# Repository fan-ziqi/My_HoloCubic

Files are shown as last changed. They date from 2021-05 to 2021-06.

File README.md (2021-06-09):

## My_Holocubic

本项目基于@peng-zhihui 稚晖君的开源项目`HoloCubic`

交流群：561533565

点击链接加入群聊【稚晖君HoloCubic交流群】：https://jq.qq.com/?_wv=1027&k=dVjVTa3X

历经不到一个月，这个项目终于快要结束了，现有的软件整合了大佬们的开源方案以及自己的改动，基本实现了`时间显示`、`天气显示`、`电脑同屏`等功能。软件方面先留一个坑吧，放假了有空再继续完善，毕竟这个小东西能实现的功能还是蛮多的，只要你异想天开。

做这个项目主要有两个原因吧
* 第一是因为这个项目真的很帅有木有，也是稚晖大佬项目中算比较简单的一个，实现起来不是很复杂
* 第二，通过这个项目可以学到`ESP32的开发以及外围电路设计`、`MPU6050在ESP平台的应用`、`串口芯片CP2102代替CH340`、`LVGL图形库的使用`、`PCBLayout及TYPE-C和天线走线规则`、`3D模型设计及3D打印`、`贴片封装（QFN封装芯片、0402电阻电容、TYPE-C/FPC座）的焊接`等知识。很同意稚晖大佬的说的`边打仗边学习`，对于我来说做项目过程中知识的储备远大于平时的学习。

项目就不多介绍了，下面是原作者的项目简介：

--------------------------------------------我是一条分割线-----------------------------------------------

# HoloCubic--多功能透明显示屏桌面站

**视频介绍：** https://www.bilibili.com/video/BV1VA411p7MD/

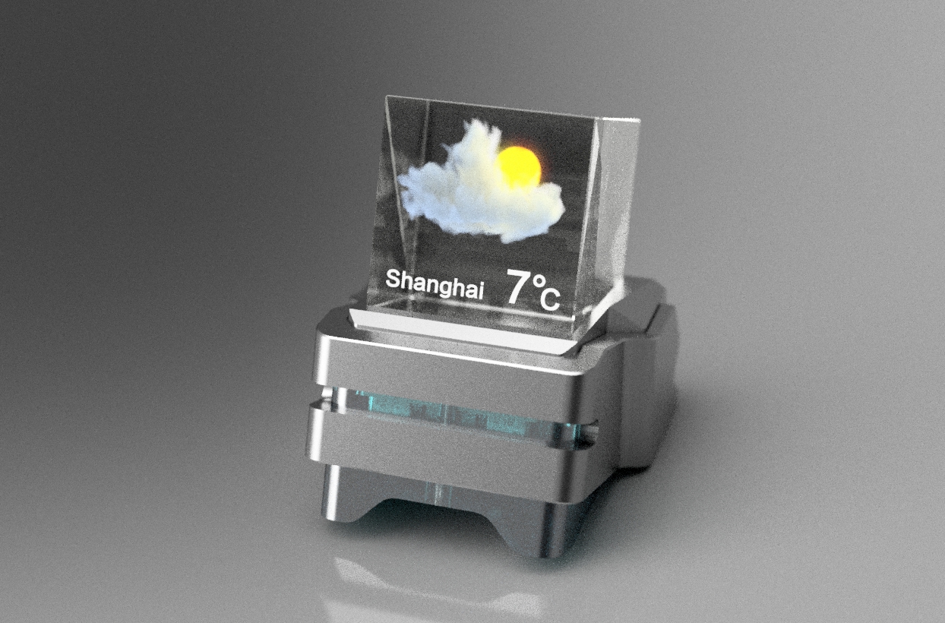
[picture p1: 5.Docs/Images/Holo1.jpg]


## 0. 关于本项目

> 稚晖君注：这是为了更新视频，缓解本人拖更两个月的尴尬，用一个周末时间赶出来的一个有意思的小玩意 :D

如视频所述，本项目有意思的地方在于使用了一个分光棱镜来设计出`伪全息显示`的效果。这个小设备总的来说功能比较多，因为搭载了WiFi和蓝牙能力可以实现很多网络应用，在本仓库中给大家提供了一个开发框架以及一些基础功能（天气、粉丝数监视器等），大家可以基于我的方案继续扩展实现更多应用。

本项目的硬件方案是基于`ESP32PICO-D4`的，乐鑫的一个很实用的MCU芯片，由于采用了SiP封装是的PCBA整板面积能做到一个硬币大小；软件方面主要是基于`lvgl-GUI`库，我移植了ST7789 1.3寸`240x240`分辨率屏幕的显示屏驱动，同时将`MPU6050`作为输入设备通过感应的方式模拟编码器键值来交互。

## 1. 硬件打样说明

**PCB打样的话暂时没发现有啥需要特别注意的。** PCB文件可以直接拿去工厂打样，两层板很便宜，器件BOM的话也都是比较常用的，整板成本在50元以内。

`Hardware`文件内目前包含两个版本的PCB电路：

* **Naive Version** ：即视频中出现的版本，板载ESP32、IMU、环境光传感器、SD卡槽、下载电路、以及两个RGB灯
* **Ironman Version** ：基于上面的版本轻微修改，删去了环境光传感器，修改了PCB形状以适配新的外壳

> 因为新款的外壳计划是使用CNC进行金属加工，因此环境光容易被遮挡，而且该功能使用场景不多所以在新版删去了。

**外壳加工** 根据自己喜欢的版本选择，`3D Model`文件夹目前包含四个版本的外壳文件：

* **Naive Version** ：即视频中出现的版本，比较简约（因为临时赶工设计的），最好使用光固化3D打印加工

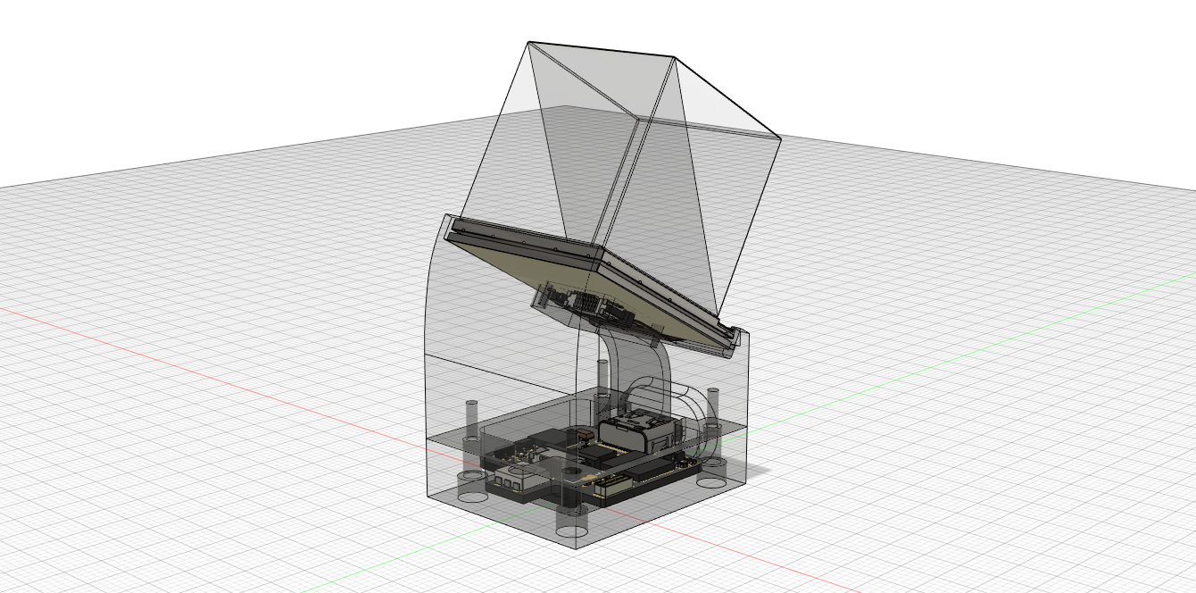
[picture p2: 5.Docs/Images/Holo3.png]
  

* **Bilibili Version** ：视频中后面出现的B站百大奖杯形式的外壳结构，适配`Naive Version`的PCB， **属于娱乐性质，非百大UP不建议采用**。

* **Metal Version** ：视频发布后全新改版的外壳结构设计，优化了布局控件整体更紧凑精致，适配`Naive Version`的PCB，该建议使用CNC加工制作

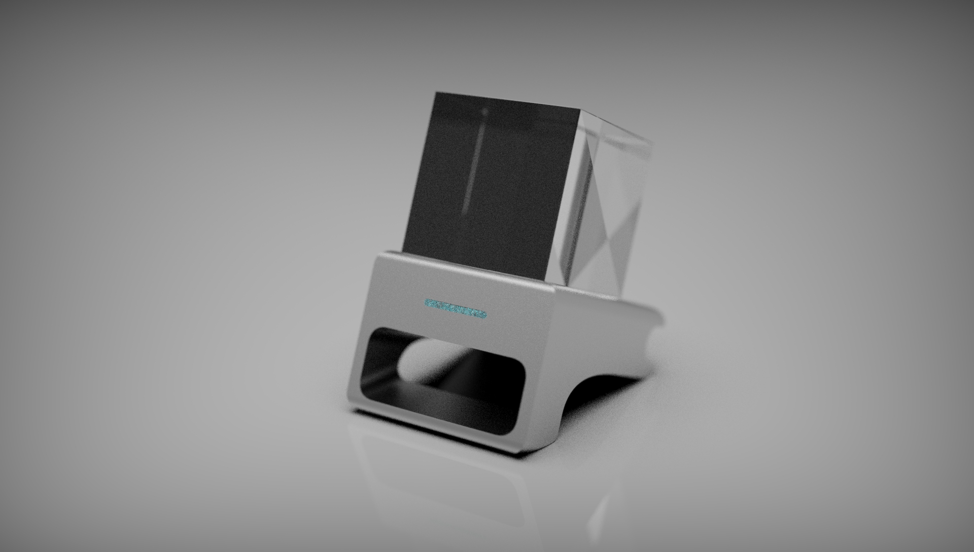
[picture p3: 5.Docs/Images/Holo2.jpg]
  

* **Ironman Version** ：新设计的野生钢铁侠风格结构件，该版本为和朋友合作设计的，后面可能会授权他联名量产，该结构适配`Ironman Version`的PCB

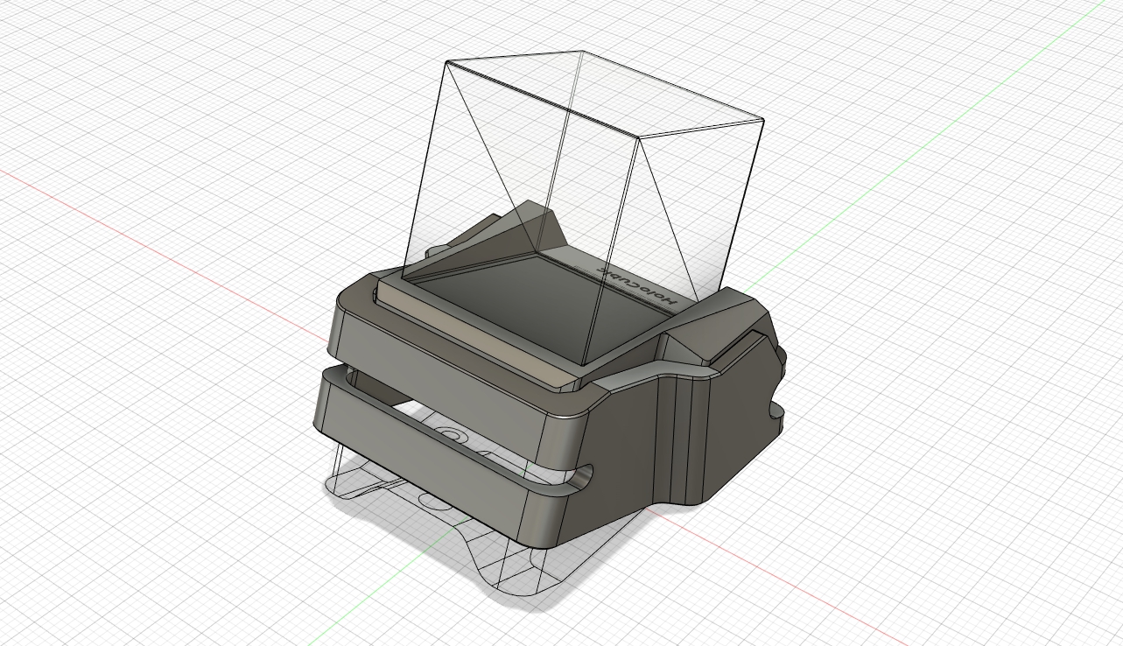
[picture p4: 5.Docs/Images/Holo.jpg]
  

> 野生钢铁侠联名的版本的结构件加工比较复杂，而且需要后期喷砂、阳极氧化等工艺所以单件制造成本很高（打听了下整套3个部件至少要1000元+），因此大家自己有加工渠道的可以用提供的文件自己去做。
>
> 没有渠道但是又想要这个版本硬件的，**我授权了那位朋友量产一小批**，他的店铺名为[Xikii](https://shop68240117.taobao.com)，是做客制化键盘很有经验的一个极客，大家感兴趣的可以去关注一下~

## 2. 固件编译说明

固件框架主要基于Arduino开发完成，玩过Arduino的基本没有上手难度了，把Firmware/Libraries里面的库安装到Arduino库目录（如果你用的是Arduino IDE的话）即可。

> 我使用的是Visual Studio上面的Visual Micro插件进行Arduino开发，因为对VS比较熟悉，大家选择自己喜欢的IDE就好了。

**然后这里需要修改一个官方库文件才能正常使用：**

首先肯定得安装ESP32的Arduino支持包（百度有海量教程），然后在安装的支持包的`esp32\hardware\esp32\1.0.4\libraries\SPI\src\SPI.cpp`文件中，**修改以下代码中的MISO为26**：

    if(sck == -1 && miso == -1 && mosi == -1 && ss == -1) {
        _sck = (_spi_num == VSPI) ? SCK : 14;
        _miso = (_spi_num == VSPI) ? MISO : 12; // 需要改为26
        _mosi = (_spi_num == VSPI) ? MOSI : 13;
        _ss = (_spi_num == VSPI) ? SS : 15;
这是因为，硬件上连接屏幕和SD卡分别是用两个硬件SPI，其中HSPI的默认MISO引脚是12，而12在ESP32中是用于上电时设置flash电平的，上电之前上拉会导致芯片无法启动，因此我们将默认的引脚替换为26。

> 也可以通过设置芯片熔丝的方式解决这个问题，不过那样的操作是一次性不可逆的，不建议这么玩。

**另外：**

由于我赶视频制作，代码都是临时写的非常杂乱有很多dirty code，因此仓库中的是所有驱动调通之后的模板代码，可以自己基于这个框架自由开发。

**APP应用代码我在整理中慢慢也会更新出来。**

## 3. Visual Studio模拟器 & 图片转换脚本

在`Software`文件夹中包含了一个Visual Studio的工程，用VS打开（需要安装C++开发组件）后可以在电脑上模拟LVGL的界面效果，改好之后代码粘贴到Arduino固件那边就可以完成界面移植。

> 这样省的每次修改都要重新交叉编译Arduino的固件，提升开发效率。

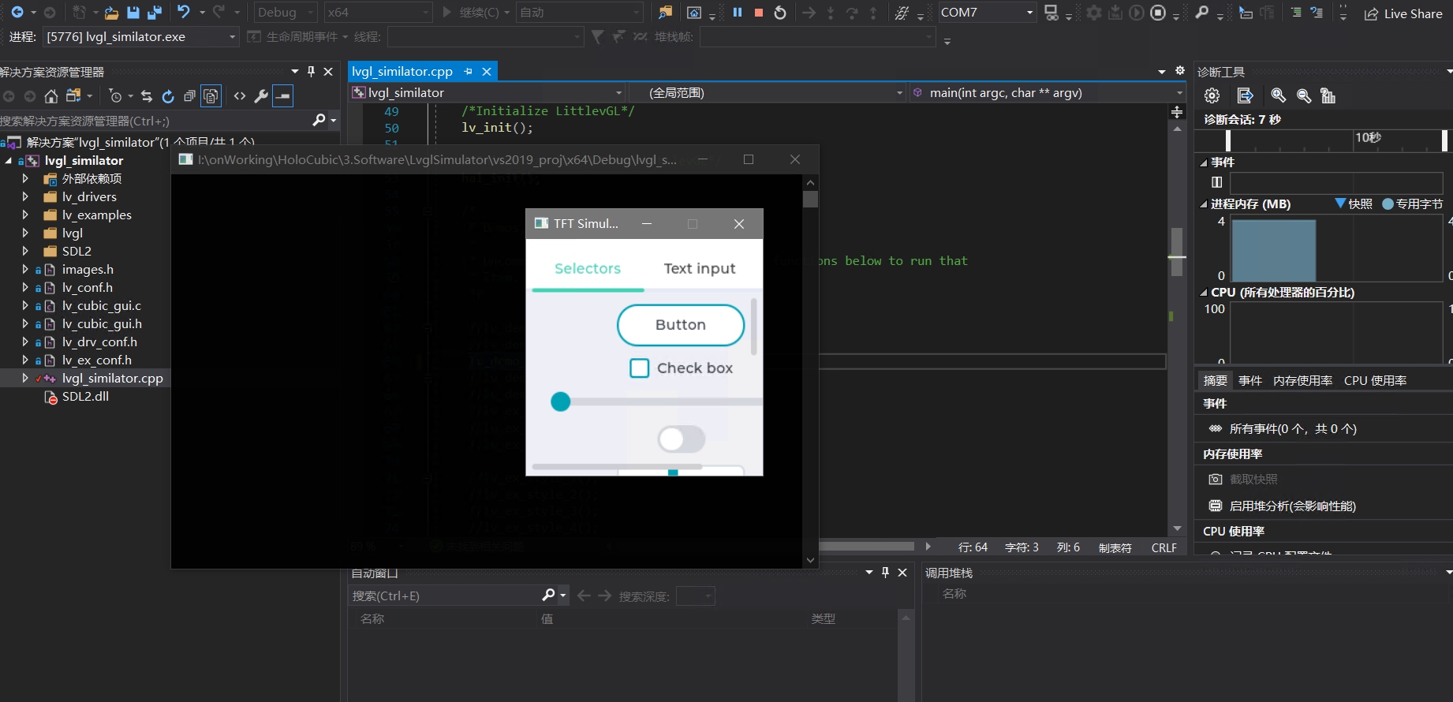
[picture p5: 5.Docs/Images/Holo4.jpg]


`ImageToHolo`文件夹下包含一个Python脚本，用于将图片转换成HoloCubic固件中用到的图像资源。

> 因为图像资源一般都比较占空间，如果全部存在ESP32的Flash中的话存不了几张，因此我在框架中移植了LVGL的FAT文件系统支持，可以将图片资源存储在SD卡内进行读取。
>
> 官方的图转换工具是在线的：[https://lvgl.io/tools/imageconverter](https://lvgl.io/tools/imageconverter) ，需要选择 `Indexed 4 colors` 格式。
>
> **但是官方工具每次只能转换一张还要上传下载很麻烦**，因此我自己写了个脚本用于批量转换。

HoloCubic用到的图片资源名为`xxx.bin`文件，大家用我提供的脚本转好后放入SD卡，然后可以像这样读取：

```
lv_obj_t* imgbtn = lv_imgbtn_create(lv_scr_act(), NULL);
lv_imgbtn_set_src(imgbtn, LV_BTN_STATE_PRESSED, "S:/dir/icon_pressed.bin");
lv_imgbtn_set_src(imgbtn, LV_BTN_STATE_RELEASED, "S:/dir/icon_released.bin");
```

其中`S:`指代SD卡根目录（注意**S是大写的**），后面就是跟Linux中的路径完全表示一致了。

> 该脚本参考了[W-Mai/lvgl_image_converter](https://github.com/W-Mai/lvgl_image_converter) 的实现。

**另外由于转换脚本的使用需要再Python环境下，如果大家不想安装环境的话，也可以用我预编译好的exe文件来转，使用方法很简单，把`jpg/png/bmp`图片拖到`holo转换器.exe`的图标上就行了（可以同时拖动多个上去），会在当前目录生成对应的`.bin`文件。**

> 转换器软件的下载地址：
>
> 链接：https://pan.baidu.com/s/11cPOVYnKkxmd88o-Ouwb5g  提取码：xlju 

## 4. 关于分光棱镜

我用的时25.4mm x 25.4mm x 25.4mm的棱镜，淘宝应该可以搜到，单个价格80元左右。

分光棱镜的固定比较麻烦，用胶水的话容易渗入屏幕导致水印，因此建议去TB搜一下`OCA胶`，这是一种`全贴合屏幕工艺`中用来粘合屏幕的固态胶，效果很不错也很便宜。

> 但是OCA粘性非常强，大家操作一定要仔细不要留气泡，不然粘上后就很难取下了。

## 其他的后续再补充，有用的话记得点星星~

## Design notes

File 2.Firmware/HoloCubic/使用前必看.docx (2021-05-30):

# ESP32相册、天气、时间显示

1. 如需使用本程序，请在arduino官网下载arduino ide，如果使用的是VS code进行编译，请见附页教程。

本项目目前实现的功能有以下几种：

1.ESP32一键配网：第一次使用，可以连接ESP32的热点进入“192.168.4.1”进行wifi的账号密码以及城市名配置

2.ESP32陀螺仪控制：在本项目主要用于切换显示

3.ESP32天气显示：在界面中，采用“心知天气”API进行天气信息获取。

4.ESP32时间显示：在界面中，采用“淘宝”API进行时间信息获取。

5.ESP32相册显示

2. 首先打开arduino ide后进入首选项配置

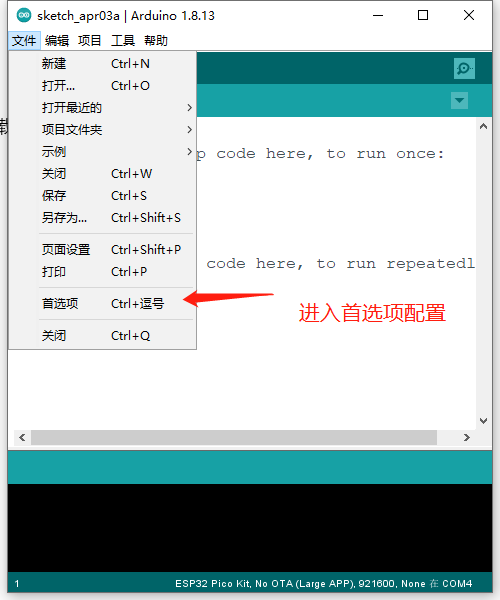
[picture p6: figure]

在“附加开发板管理器网址”中添加 “https://dl.espressif.com/dl/package_esp32_index.json”

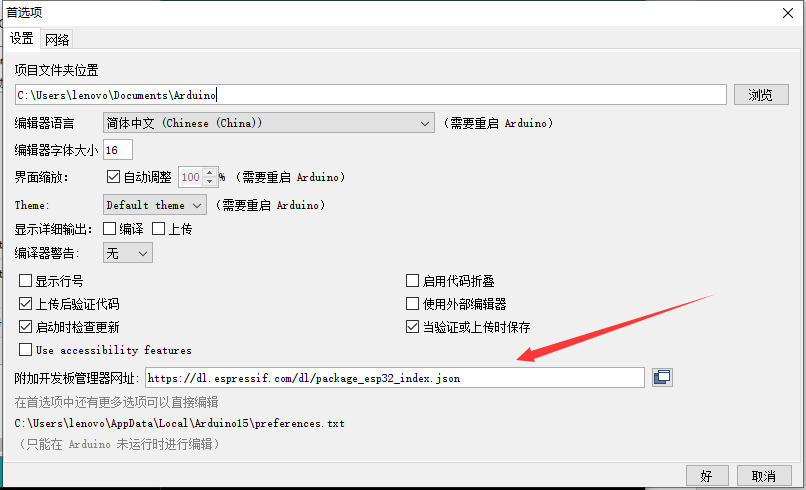
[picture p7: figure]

之后打开“工具”中的“开发板管理器”

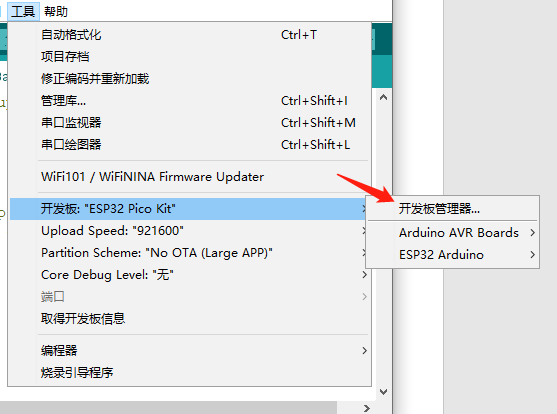
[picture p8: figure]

下载ESP32开发板,我这里已经下载了，所以显示的是更新，如果没有下载就安装一下，安装时候安装最新版本即可，否则可能有些功能无法使用。

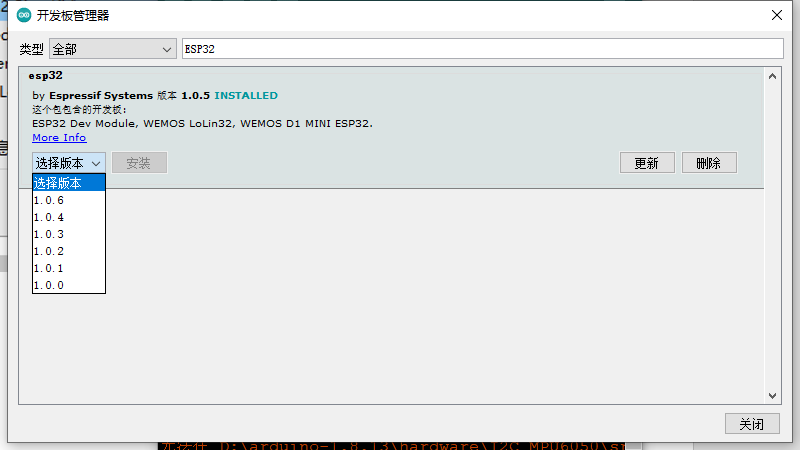
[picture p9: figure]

随后将文件夹内带的“Libraries”文件夹内的库文件放到“C:\Users\lenovo\Documents\Arduino\libraries”即可使用。

注意，使用此程序需要将工具中的“Partition Scheme”设置为“NO OTA”模式。

# ESP32一键配网

此功能主要是分为两部分，首先上电后会检测SD卡的wifi.txt文件是否有已配置的内容，如果有则尝试连接，连接成功后会进入页面显示。如果连接不成功则进入AP热点配网模式，ESP32会自身开启热点，用户连接热点后进行wifi的配置。

热点默认ssid为“ESP32_Config”，默认密码为“12345678”，进入默认ip地址“192.168.4.1”即可配置“WiFi SSID”、“WiFi PASS”、“City Name”三个参数，City Name参数主要作为天气显示调用api时上传的位置信息。

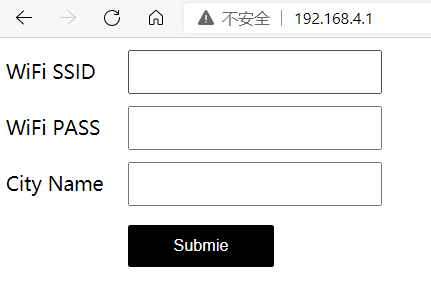
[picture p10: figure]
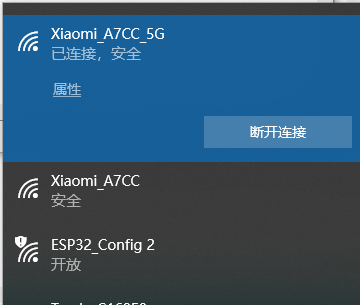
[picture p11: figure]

填写完成后使用“GET”协议下发到ESP32上，随后存储进SD卡内。下次会自动检测是否有上次配置的wifi环境，如果有会自动重连。中间断线也可重新连接。

# ESP32陀螺仪控制

此设备装载MPU6050陀螺仪，可以检测 6自由度或6轴的IMU传感器，这意味着它提供了6个值作为输出：包含加速度计的3个值和陀螺仪的3个值。MPU 6050是一种基于MEMS（微机电系统）技术的传感器，它将加速度计和陀螺仪嵌入到一块芯片中，芯片使用的I2C通信协议。

在本项目中主要用于角度感知，利用x轴和y轴的变化来控制页面的切换。如果自己感觉角度灵敏可以调节imu.cpp文件下的ax和ay的判定数值。

# ESP32天气显示

天气显示主要运用lvgl库来对屏幕进行绘制，数据的获取主要获取的“心知天气”的天气api数据“ https://api.seniverse.com/v3/weather/now.json?key=" + key + "&location=" + cityname + "&language=" + language + "&unit=" + unit”，如需使用请申请心知天气账号，可以免费开通天气api，不过有访问频率限制，所以此处不公开私钥了，在程序中把自己的私钥赋值给给37行的“key”变量即可。

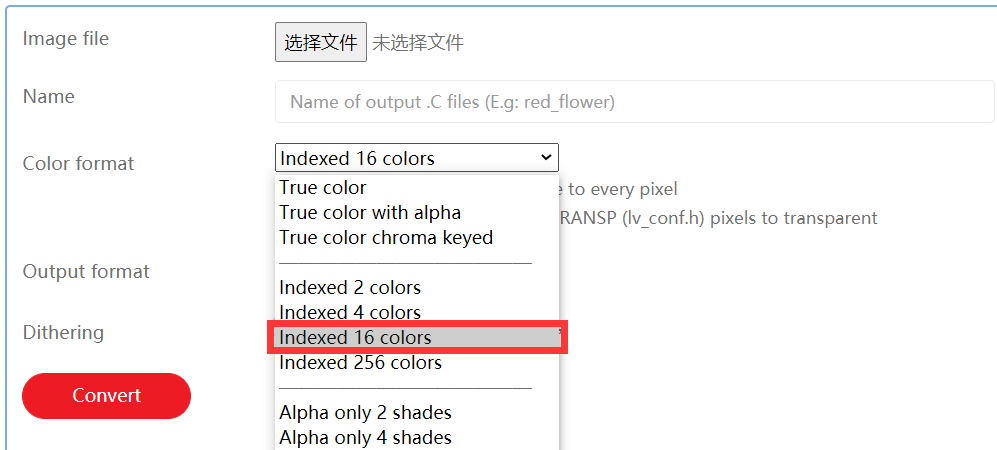
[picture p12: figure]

常用的天气图片利用lvgl的官方转换器https://lvgl.io/tools/imageconverter 转换为c数组，格式为Indexed 16 colors。

随后把转换完成的c文件复制下来粘贴到image.h文件中，复制格式与程序中相同即可。

注：图片分辨率需为240*240，否则屏幕则显示不下相应图片。

不常用的图片则可以转换成bin文件存储到SD卡中，这样可以省下一些程序存储空间用来增加功能。

转换格式为下图的标准格式，本程序内涵weather文件夹，已做好image转换。如果想要自己重新制作一套，需参照心知天气的天气代码来重新生成文件，文件名对应其天气代码即可。

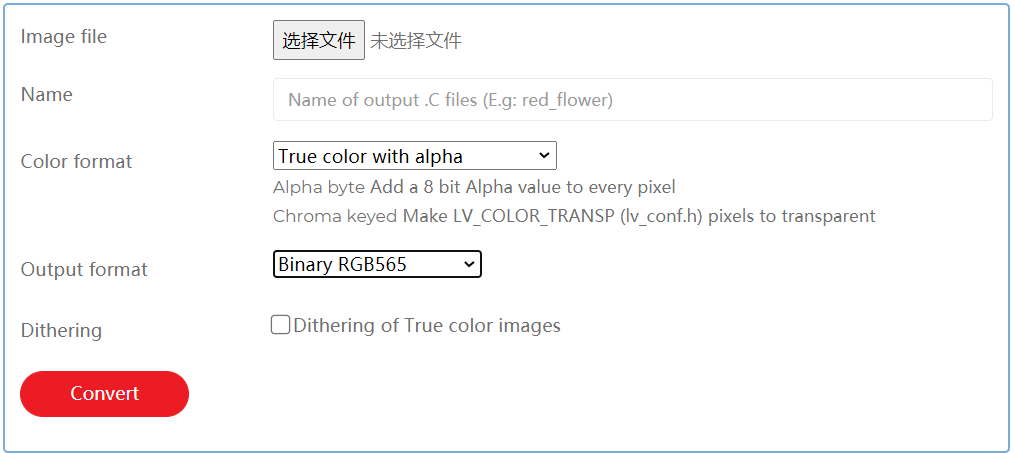
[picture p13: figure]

# ESP32时间显示

此功能主要采集的“淘宝”的时间api http://api.m.taobao.com/rest/api3.do?api=mtop.common.getTimestamp，此api免费使用，所以不必担心期限问题。在程序中利用arduino的rtc.setTime(Time);函数来进行时间的计算，把采集到的“data”数据传入到此函数中，会返回对应的年月日时分。在显示上加了一个字符串拼接，因为在时间分小于10的时候，在分的个位前没有0的显示，所以加了一个字符串拼接来显示0。字体则使用的为lvgl自带的字体。

# ESP32相册显示

此功能读取的为SD卡中image文件夹下的bin文件，将自己的图片在官网转换，转换格式为下图，需要自己修改文件名格式为（0.bin，1.bin，2.bin，3.bin……）。随后对ESP32进行上倾斜（x轴）就可进入相册显示界面，下倾斜（x轴）则退出相册显示，进入常规显示。

目前现在相册可以存储250张，如果认为空间不够使用，请更改SdCard.cpp文件下listDir函数内的“File_name”数组的空间大小即可。

建议最大不要超过10000，这样会比较浪费内存空间。

后续功能待开发……

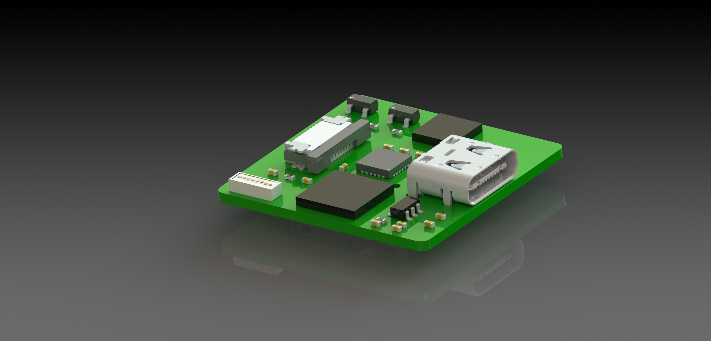
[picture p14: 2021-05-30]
1.Hardware/PCB/HoloCubic/Untitled.JPG

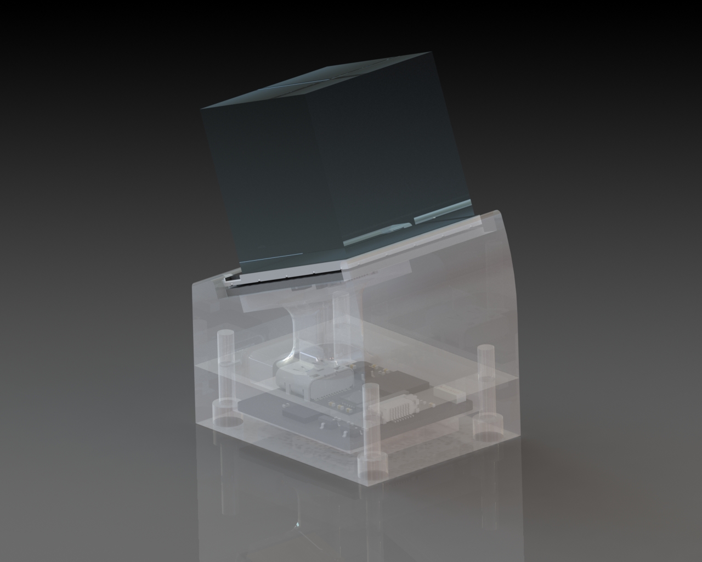
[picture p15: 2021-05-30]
4.3D_Model/SW/渲染.JPG

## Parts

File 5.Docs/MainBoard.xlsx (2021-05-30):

Comment | Description | Designator | Footprint | LibRef | Quantity
2.2nF | Capacitor | C8 | CAP_0402 | 电容-0402 | 1 | 15
10nF | Capacitor | C3, C6 | CAP_0402 | 电容-0402 | 2 | 30
100nf | Capacitor | C1, C5, C7, C10, C11 | CAP_0402 | 电容-0402 | 3 | 45
1uF | Capacitor | C9 | CAP_0402 | 电容-0402 | 1 | 15
10uF | Capacitor | C2, C4 | CAP_0402 | 电容-0402 | 2 | 30
0R | Resistor | R2 | RES_0402 | 电阻-0402 | 1 | 15
200R | Resistor | R3 | RES_0402 | 电阻-0402 | 1 | 15
10K | Resistor | R1, R6, R7, R8, R9, R10 | RES_0402 | 电阻-0402 | 6 | 90
12K | Resistor | R4, R5 | RES_0402 | 电阻-0402 | 2 | 30
CP2102 | USB转TTL | U1 | QFN-28 | CP2102 | 1 |  | 3
MPU6050 | 六轴传感器 | U3 | QFN-24 | MPU6050 | 1 |  | 4
ESP32_SIP |  | U4 | QFN-48_7X7 | ESP32-PICO | 1 |  | 4
LP2992 3V3 | LDO | U2 | SOT23-5 | LP2992 | 1
S8050 |  | VT1, VT2 | SMT_TRIODE_NPN | SMT_TRIODE_NPN | 2
RAINSUN |  | A1 | ANT-Rainsun-AN5120 | ANT-Rainsun-AP5120 | 1
4x4x1.5 | 贴片4x4轻触开关 | KEY1 |  | TSW SMD-4x4 | 1
TF_Card | TF卡座 | TF1 | Micro SD | TF_Card | 1
Type-C |  | USB1 | Type-C-TOP | USB-Type-C-TOP | 1
FFC_0.5_8 | FFC | CON1 | FFC_0.5_8 | FFC_0.5_8 | 1

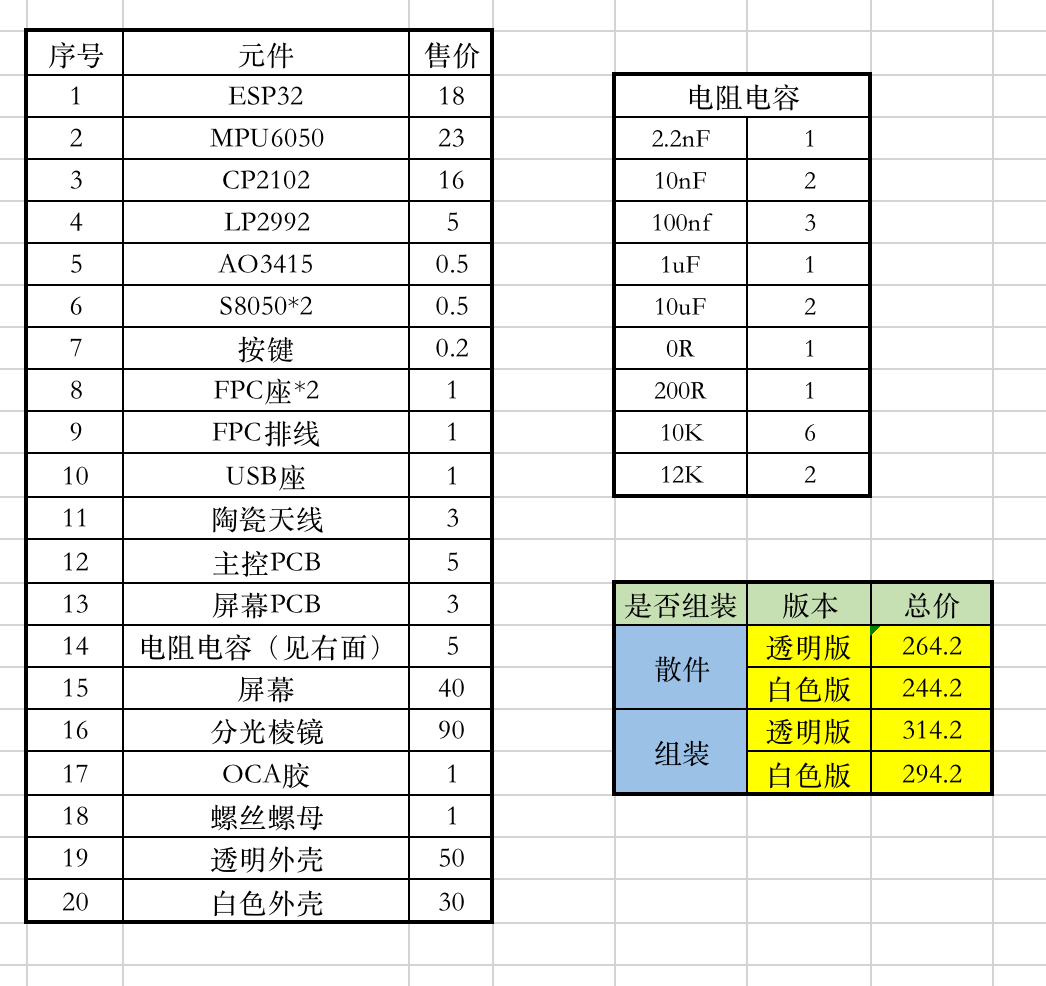
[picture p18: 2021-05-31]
销售清单.png

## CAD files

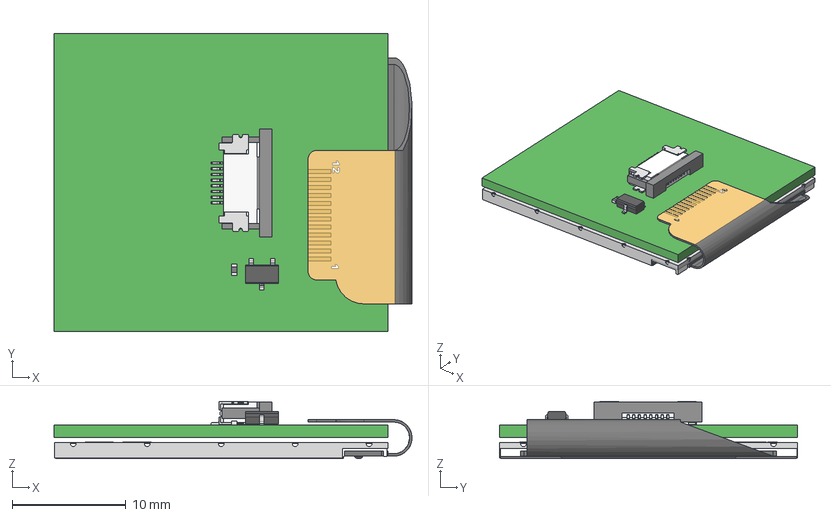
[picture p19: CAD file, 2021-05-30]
1.Hardware/PCB/HoloCubic/LCD/LCD.step
31.5 x 26.2 x 5.03 mm
Mid_Body
Open_CASCADE_STEP_translator_6.8_20.2.1 x 2
Mark
SOT-23-3
ffc_fpc_affc20-16-050-shb-t_(2)
1.3_TFT_IPS_-_Flush_Reverse_Mount

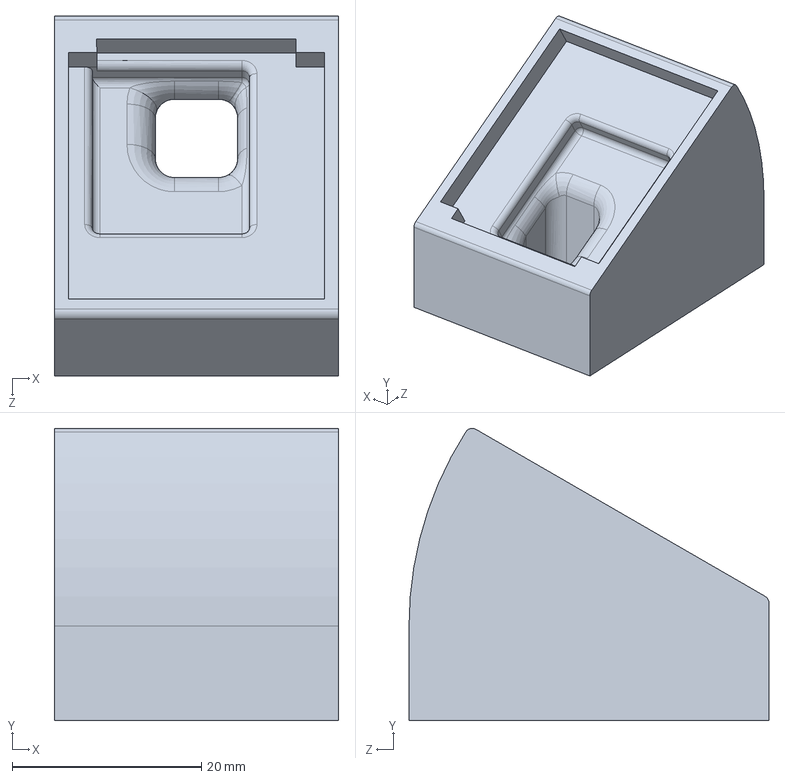
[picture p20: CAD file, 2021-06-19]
4.3D_Model/SW/up.SLDPRT
30.0 x 30.9 x 38.0 mm

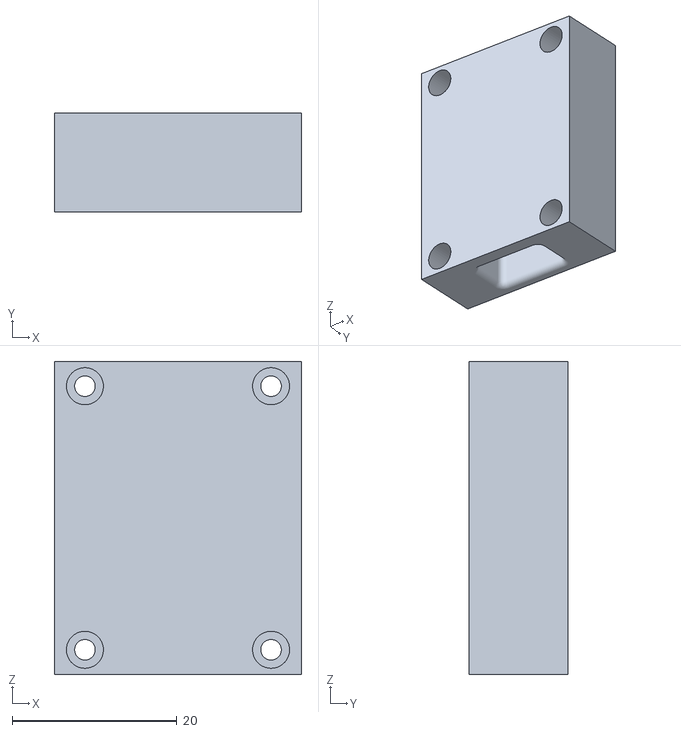
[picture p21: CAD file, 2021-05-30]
4.3D_Model/low.STL
30.0 x 12.0 x 38.0

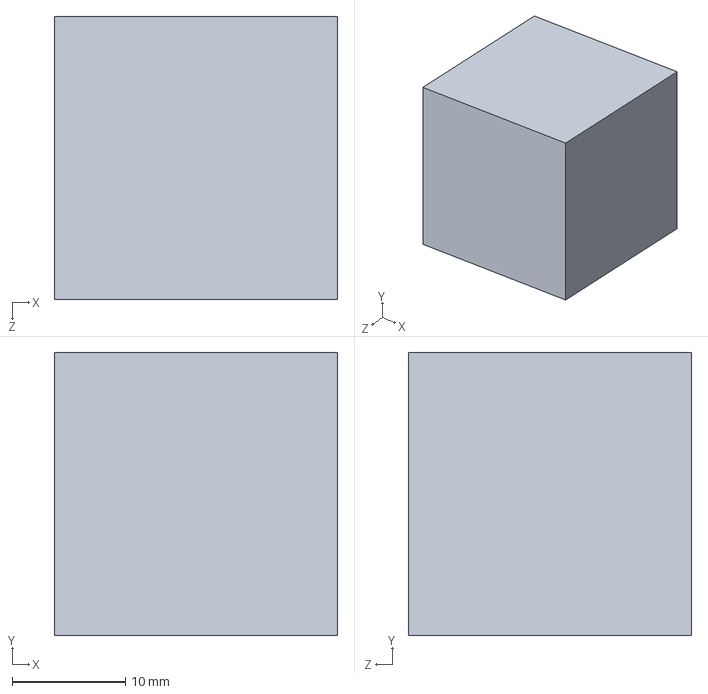
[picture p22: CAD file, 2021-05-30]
4.3D_Model/SW/CUBE.SLDPRT
25.0 x 25.0 x 25.0 mm

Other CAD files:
4.3D_Model/up_4_0.STL
4.3D_Model/SW/up_4_0.SLDPRT
4.3D_Model/up.STL
4.3D_Model/SW/low.SLDPRT
4.3D_Model/SW/up.STL

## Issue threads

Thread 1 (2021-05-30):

BUGs

fan-ziqi, 2021-05-30:
请在此提交软硬件bug，也可创建新issue，我看到后会邮箱回复

fan-ziqi, 2021-05-30:
作者太帅怎么办？

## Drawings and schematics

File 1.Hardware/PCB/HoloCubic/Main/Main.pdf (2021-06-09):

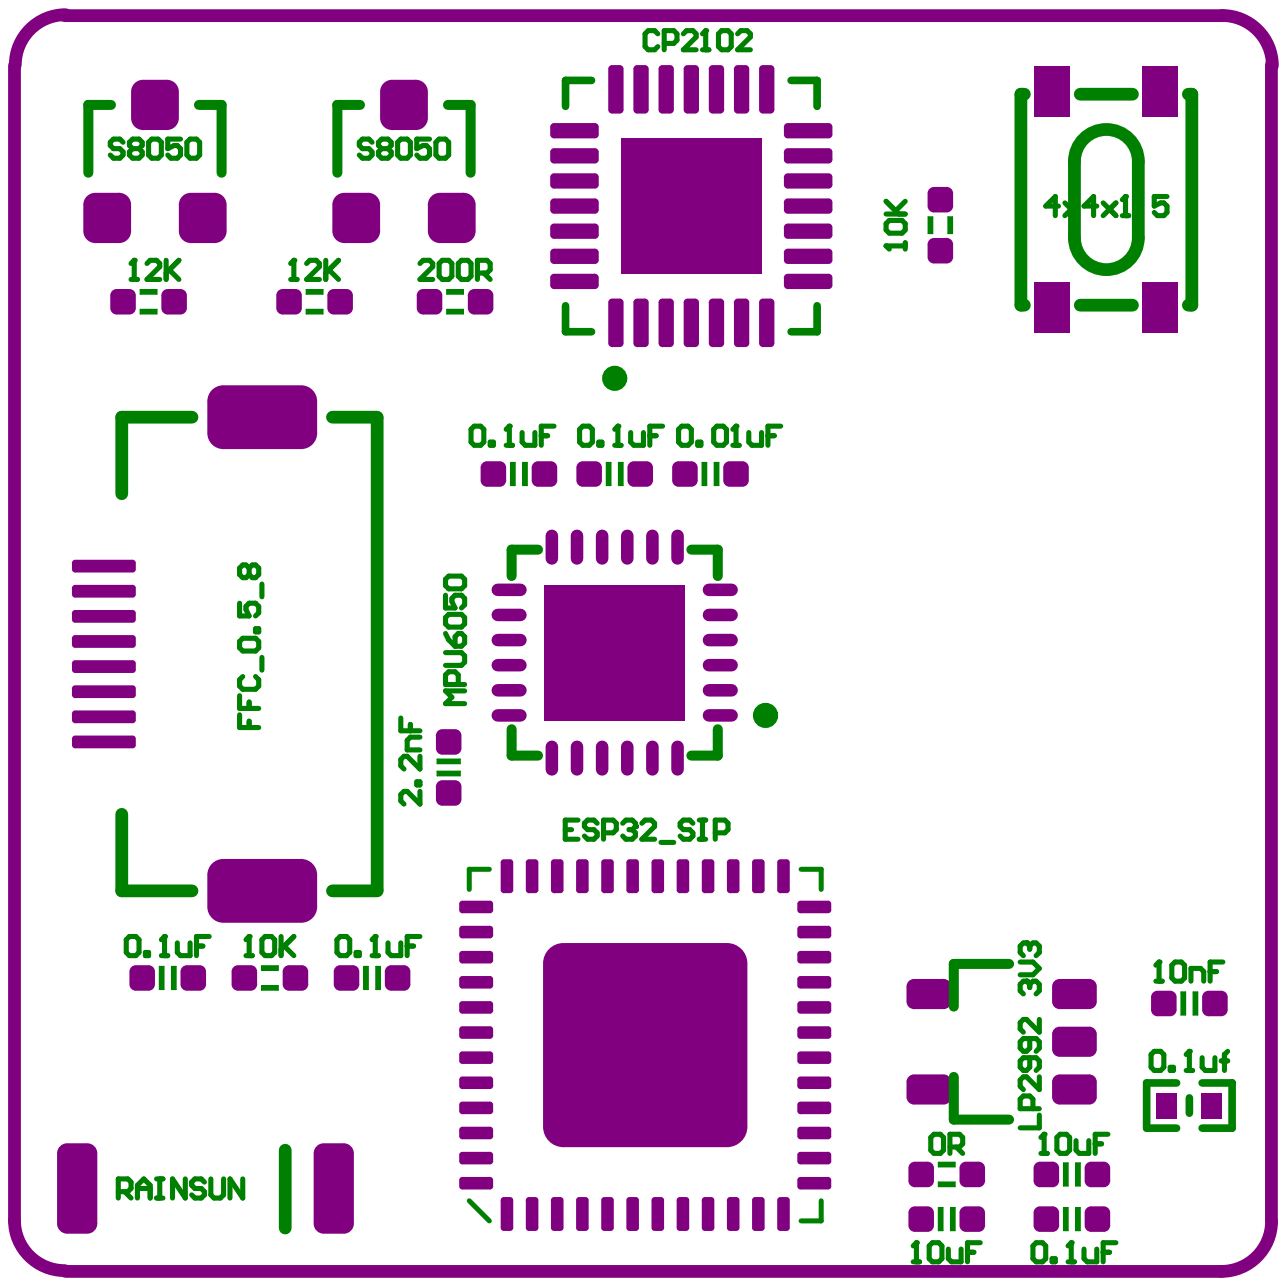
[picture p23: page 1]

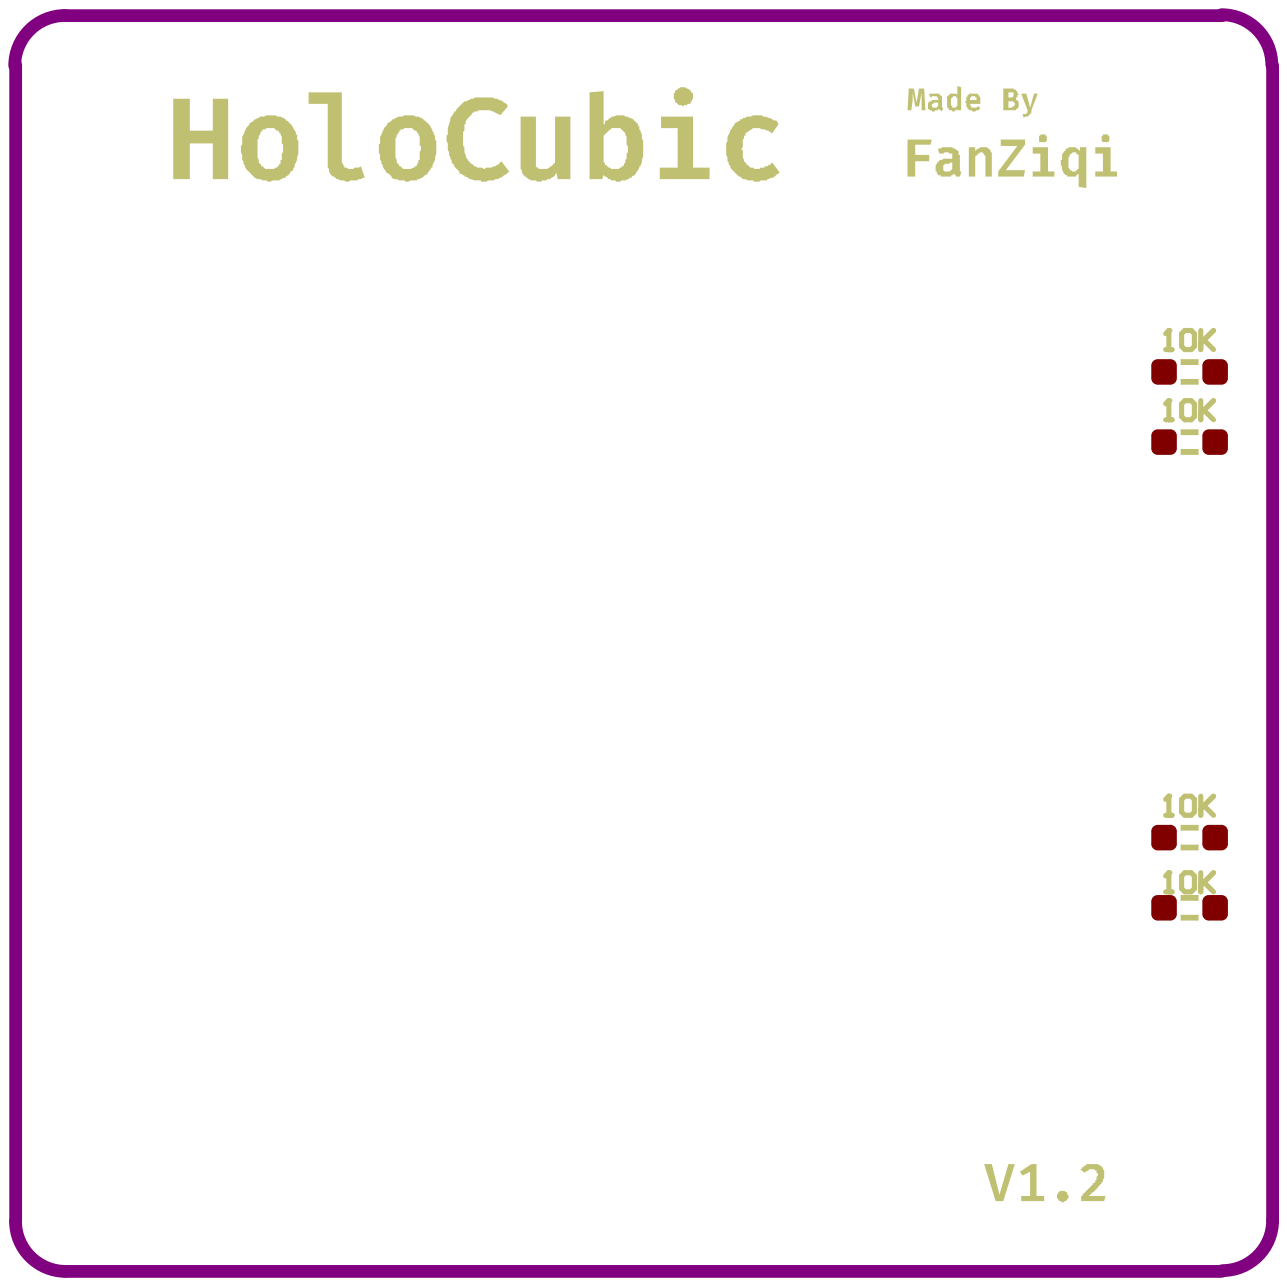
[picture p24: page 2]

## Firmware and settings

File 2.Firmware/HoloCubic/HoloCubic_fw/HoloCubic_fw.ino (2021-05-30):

#include "display.h"
#include "imu.h"
#include "network.h"
#include "sd_card.h"
#include "lv_port_indev.h"
#include "lv_cubic_gui.h"
#include "lv_demo_encoder.h"
#include "lv_port_fatfs.h"
#include <ESP32Time.h>
#include <ESPmDNS.h>
#include <WebServer.h>
#include <WiFiMulti.h>

#include <TFT_eSPI.h>
extern TFT_eSPI tft;
TFT_eSprite clk = TFT_eSprite(&tft);

/*** Component objects **7*/
Display screen;
IMU mpu;
SdCard tf;
Network wifi;
ESP32Time rtc;
long int Time;
int tian;
int zero_flag;
long time1;
const char* AP_SSID  = "ESP32_Config"; //热点名称
const char* AP_PASS  = "12345678";  //密码
#define ROOT_HTML  "<!DOCTYPE html><html><head><title>WIFI Config by lwang</title><meta name=\"viewport\" content=\"width=device-width, initial-scale=1\"></head><style type=\"text/css\">.input{display: block; margin-top: 10px;}.input span{width: 100px; float: left; float: left; height: 36px; line-height: 36px;}.input input{height: 30px;width: 200px;}.btn{width: 120px; height: 35px; background-color: #000000; border:0px; color:#ffffff; margin-top:15px; margin-left:100px;}</style><body><form method=\"GET\" action=\"connect\"><label class=\"input\"><span>WiFi SSID</span><input type=\"text\" name=\"ssid\"></label><label class=\"input\"><span>WiFi PASS</span><input type=\"text\"  name=\"pass\"></label><label class=\"input\"><span>City Name</span><input type=\"text\" name=\"cityname\"></label></label><input class=\"btn\" type=\"submit\" name=\"submit\" value=\"Submie\"></form></body></html>"
WebServer server(80);
TimerHandle_t xTimer_rest;
WiFiMulti wifiMulti;
uint8_t count_down;//自动配网倒计时s
uint8_t wifi_flag;
uint8_t resr_count_down = 100;//重启倒计时s
String  key = "SqTlWHkGy6Ig6XcZG"; //填写天气秘钥
String  cityname;		 //显示的城市
String  language = "zh-Hans";
String  unit = "c";
String Time_api = "http://api.m.taobao.com/rest/api3.do?api=mtop.common.getTimestamp";
int Timey;
int Timem;
int Timed;
int Timeh;
int Timemin;

char Timey1[8];
char Timem1[8];
char Timed1[8];
char Timeh1[8];
char Timemin1[8];
char zero[8];
char tiangqii[8];
char cityname1[10];

const char* Timey2 = Timey1;
const char* Timem2 = Timem1;
const char* Timed2 = Timed1;
const char* Timeh2 = Timeh1;
const char* Timemin2 = Timemin1;
const char* zeroo = zero;
const char* tianqq = tiangqii;



void restCallback(TimerHandle_t xTimer );
////####################################################################################################
//// 文件上传SD卡
////####################################################################################################
//void handleFileUpload(){//网络服务处理函数
//  upload_flag = true;//正在进行上传
//  if(server.uri() != "/") return;
//  HTTPUpload& upload = server.upload();
//  String filename;
//  char *file_sd;
//  if(upload.status == UPLOAD_FILE_START){//开启下载上传的文件
//    filename = upload.filename;
//    if(!filename.startsWith("/"))
//    {
//      filename = "/loge"+String(tft_num)+".jpg";//如果文件开头没有/则添加/ 并且对该图片添加计数尾缀
//      tft_num++;//文件数+1
//      EEPROM.write(20,tft_num);//将数据保存
//      EEPROM.commit();
//    }
//    Serial.print("handleFileUpload Name: "); Serial.println(filename);//打印文件名
//
//    SD.remove(filename);
//    fsUploadFile = SD.open(filename, "w");//将上传的文件保存
//    filename = String();
//  } else if(upload.status == UPLOAD_FILE_WRITE){
//    if(fsUploadFile)
//      fsUploadFile.write(upload.buf, upload.currentSize);//将上传文件写入SD卡
//  } else if(upload.status == UPLOAD_FILE_END){
//    if(fsUploadFile)
//      fsUploadFile.close();
//  }
//}
void UpdateWeather(void)
{
  int TianQi = wifi.getTianqi("https://api.seniverse.com/v3/weather/now.json?key=" + key + "&location=" + cityname + "&language=" + language + "&unit=" + unit); //如果要改城市这里也需要修改
  itoa(TianQi, tiangqii, 10);
  Serial.println(tian);
  lv_holo_cubic_gui(tianqq, Timey2, Timem2, Timed2, Timeh2, Timemin2, cityname.c_str(), 1, WeatherCode);
}

void UpdateTime_RTC(void)
{
  Timey = rtc.getYear();
  Timem = rtc.getMonth() + 1;
  Timed = rtc.getDay();
  Timeh = rtc.getHour(true) + 8;
  Timemin = rtc.getMinute();
  itoa(Timey, Timey1, 10);
  itoa(Timem, Timem1, 10);
  itoa(Timed, Timed1, 10);
  itoa(Timeh, Timeh1, 10);
  itoa(Timemin, Timemin1, 10);
  if (Timemin < 10)
  {
    strcpy(zero, "0");
    strcat(zero,Timemin1);
    strcpy(Timemin1,zero);
  }
  lv_holo_cubic_gui(tianqq, Timey2, Timem2, Timed2, Timeh2, Timemin2, cityname.c_str(), 2, WeatherCode);
}
void ap_jiance(boolean result)
{
  if (result)
  {
    IPAddress myIP = WiFi.softAPIP();

    //打印相关信息

    Serial.println("");

    Serial.print("Soft-AP IP address = ");

    Serial.println(myIP);

    Serial.println(String("MAC address = ")  + WiFi.softAPmacAddress().c_str());

    Serial.println("waiting ...");

    xTimer_rest = xTimerCreate("xTimer_rest", 1000 / portTICK_PERIOD_MS, pdTRUE, ( void * ) 0, restCallback);

    xTimerStart( xTimer_rest, 0 );  //开启定时器


  } else {  //开启热点失败

    Serial.println("WiFiAP Failed");

    delay(3000);

    ESP.restart();  //复位esp32

  }
  if (MDNS.begin("esp32")) {

    Serial.println("MDNS responder started");
  }
}
void wifi_cun(String ssid, String pass, String cityname)
{
  tf.deleteFile("/wifi.txt");
  tf.writeFile("/wifi.txt", ssid.c_str(), pass.c_str(), cityname.c_str());
  String ssid_txt = tf.readFileLine("/wifi.txt", 1);    // line-1 for WiFi ssid
  String password_txt = tf.readFileLine("/wifi.txt", 2);  // line-2 for WiFi password
  cityname = tf.readFileLine("/wifi.txt", 3);  // line-3 for tianqi
  Serial.println(ssid_txt);
  Serial.println(password_txt);
  Serial.println(cityname);
  tian = wifi.getTianqi("https://api.seniverse.com/v3/weather/now.json?key=" + key + "&location=" + cityname + "&language=" + language + "&unit=" + unit);
  Serial.println(tian);
  Time = wifi.getTimestamp(Time_api); //nowapi时间API
  Serial.println(Time);
  rtc.setTime(Time);

  char tiangqi[8];
  /*About Time Start*/

  Timey = rtc.getYear();
  Timem = rtc.getMonth() + 1;
  Timed = rtc.getDay();
  Timeh = rtc.getHour(true) + 8;
  Timemin = rtc.getMinute();
  itoa(Timey, Timey1, 10);
  itoa(Timem, Timem1, 10);
  itoa(Timed, Timed1, 10);
  itoa(Timeh, Timeh1, 10);
  itoa(Timemin, Timemin1, 10);
  if (Timemin < 10)
  {
    strcpy(zero, "0");
    strcat(zero,Timemin1);
    strcpy(Timemin1,zero);
  }
  itoa(tian, tiangqi, 10);
  const char* tianq = tiangqi;

  Serial.println("-------------------------------------");
  Serial.println(tianq);
  Serial.println(Timey2);
  Serial.println(Timem2);
  Serial.println(Timed2);
  Serial.println(Timeh2);
  Serial.println(Timemin2);
  Serial.println(cityname);
  Serial.println(0);
  Serial.println(WeatherCode);
  Serial.println("-------------------------------------");
  lv_holo_cubic_gui(tianq, Timey2, Timem2, Timed2, Timeh2, Timemin2, cityname.c_str(), 0, WeatherCode);
}
void wifi_getdata()
{
  tian = wifi.getTianqi("https://api.seniverse.com/v3/weather/now.json?key=" + key + "&location=" + cityname + "&language=" + language + "&unit=" + unit);
  Serial.println(tian);
  Time = wifi.getTimestamp(Time_api); //nowapi时间API
  Serial.println(Time);
  rtc.setTime(Time);
  char tiangqi[8];
  /*About Time Start*/
  Timey = rtc.getYear();
  Timem = rtc.getMonth() + 1;
  Timed = rtc.getDay();
  Timeh = rtc.getHour(true) + 8;
  Timemin = rtc.getMinute();
  itoa(Timey, Timey1, 10);
  itoa(Timem, Timem1, 10);
  itoa(Timed, Timed1, 10);
  itoa(Timeh, Timeh1, 10);
  itoa(Timemin, Timemin1, 10);
  itoa(tian, tiangqi, 10);
  if (Timemin < 10)
  {
    strcpy(zero, "0");
    strcat(zero,Timemin1);
    strcpy(Timemin1,zero);
  }
  const char* tianq = tiangqi;
  lv_holo_cubic_gui(tianq, Timey2, Timem2, Timed2, Timeh2, Timemin2, cityname.c_str(), 0, WeatherCode);
}


byte loadNum = 6;
void loading(byte delayTime){
  clk.setColorDepth(8);
  
  clk.createSprite(200, 50);
  clk.fillSprite(0x0000);

  clk.drawRoundRect(0,0,200,16,8,0xFFFF);
  clk.fillRoundRect(3,3,loadNum,10,5,0xFFFF);
  clk.setTextDatum(CC_DATUM);
  clk.setTextColor(TFT_GREEN, 0x0000); 
  clk.drawString("Connecting to WiFi",100,40,2);
  clk.pushSprite(20,110);
  clk.deleteSprite();
  loadNum += 1;
  if(loadNum>=194){
    loadNum = 194;
  }
  delay(delayTime);
}


void ap_peizhi()
{
  //首页

  server.on("/", []() {

    server.send(200, "text/html", ROOT_HTML);

  });
  //连接
  server.on("/connect", []() {


    server.send(200, "text/html", "<html><body><h1>successd,conning...</h1></body></html>");


    WiFi.softAPdisconnect(true);

    //获取输入的WIFI账户和密码

    String ssid = server.arg("ssid");

    String pass = server.arg("pass");

    cityname = server.arg("cityname");

    Serial.println("WiFi Connect SSID:" + ssid + "  PASS:" + pass);

    //设置为STA模式并连接WIFI

    WiFi.mode(WIFI_STA);

    WiFi.begin(ssid.c_str(), pass.c_str());


    resr_count_down = 100;

    xTimerStop(xTimer_rest, 0);


    uint8_t Connect_time = 0; //用于连接计时，如果长时间连接不成功，复位设备


    while (WiFi.status() != WL_CONNECTED) 
    {  //等待WIFI连接成功

      delay(500);
      Connect_time ++;

      if (Connect_time > 80) {  //长时间连接不上，复位设备

        Serial.println("Connection timeout, check input is correct or try again later!");

        delay(3000);

        ESP.restart();
      }
    }


    wifi_cun(ssid, pass, cityname);
    wifi_flag = 0;
    count_down = 0;
  });
  server.begin();
}
extern int File_num;//相册文件数量
void setup()
{
  Serial.begin(115200);

  /*** Init screen ***/
  screen.init();
  screen.setBackLight(0.6);//0.1

  /*** Init IMU as input device ***/
  lv_port_indev_init();
  mpu.init();

  /*** Init micro SD-Card ***/
  tf.init();
  lv_fs_if_init();
  String ssid = tf.readFileLine("/wifi.txt", 1);		// line-1 for WiFi ssid
  String password = tf.readFileLine("/wifi.txt", 2);	// line-2 for WiFi password
  cityname   = tf.readFileLine("/wifi.txt", 3);  // line-2 for WiFi password
  Serial.println(ssid);
  Serial.println(password);
  Serial.println(cityname);
  tf.listDir("/image", 250);

  /*** Read WiFi info in SD-Card, then scan & connect WiFi ***/
  if (count_down <= 10)
  {
    wifi.init(ssid, password);
    Serial.println("正在自动配网");
    Serial.println(wifi_flag);

    while (WiFi.status() != WL_CONNECTED) 
    {  //等待WIFI连接成功
      for(byte n=0;n<10;n++)
      { //每500毫秒检测一次状态
        loading(50);
      }
    }
    while(loadNum < 194)
    { //让动画走完
      loading(1);
    }

    if (wifi_flag == 0)
    {
      wifi_getdata();
    }
  }
  if (wifi_flag == 1) {
    WiFi.mode(WIFI_AP);//配置为AP模式
    boolean result = WiFi.softAP(AP_SSID, AP_PASS);//开启WIFI热点
    ap_jiance(result);
    ap_peizhi();
  }
  time1 = millis();
}

int flag = 0;
float fade = 0;
extern int tmp;
extern boolean image_flag;
int image_flag_num = 0;
int page = 0;
long previousMillis1 = 0;
long previousMillis2 = 0;
long Weatherinterval = 900000;
long Timeinterval = 10000;
unsigned long previousMillis = 0;
boolean delayState = false;
boolean doDelayMillisTime(long interval , boolean state);
void loop()
{
  server.handleClient();
  // run this as often as possible ��
  while (WiFi.status() == WL_CONNECTED) {  //等待WIFI连接成功

    //WIFI已连接
    screen.routine();

    mpu.update(500);

    delay(10);
    if (image_flag == 1)
    {
      xiangce(File_num);
      lv_scr_load_anim(src, LV_SCR_LOAD_ANIM_NONE , 100, 0  , false);
      if (doDelayMillisTime(3000 , false) == true) {
        image_flag_num++;
        delayState = false;
      }

      if (image_flag_num >= File_num)
      {
        image_flag_num = 0;
      }
      page = 0;
      tmp = 1;
    }
    else
    {
      image_flag_num = 0;
      if (tmp == 1 & page == 0)
      {
        lv_scr_load_anim(scr2, LV_SCR_LOAD_ANIM_MOVE_LEFT, 500, 300, false);
        page = 1;
        tmp = 0;
      }
      if (tmp == 1 & page == 1)
      {
        lv_scr_load_anim(scr3, LV_SCR_LOAD_ANIM_MOVE_LEFT, 500, 300, false);
        page = 2;
        tmp = 0;
      }
      if (tmp == 1 & page == 2)
      {
        lv_scr_load_anim(scr1, LV_SCR_LOAD_ANIM_MOVE_LEFT, 500, 300, false);
        page = 0;
        tmp = 0;
      }
      if (tmp == 2 & page == 0)
      {
        lv_scr_load_anim(scr3, LV_SCR_LOAD_ANIM_MOVE_RIGHT, 500, 300, false);
        page = 2;
        tmp = 0;
      }
      if (tmp == 2 & page == 1)
      {
        lv_scr_load_anim(scr1, LV_SCR_LOAD_ANIM_MOVE_RIGHT, 500, 300, false);
        page = 0;
        tmp = 0;
      }
      if (tmp == 2 & page == 2)
      {
        lv_scr_load_anim(scr2, LV_SCR_LOAD_ANIM_MOVE_RIGHT, 500, 300, false);
        page = 1;
        tmp = 0;
      }

      if (millis() - time1 > 5000 && !flag)
      {
        flag = 1;
        lv_scr_load_anim(scr1, LV_SCR_LOAD_ANIM_NONE, 10, 0, false);
      }

      if (millis() - previousMillis1 >= Weatherinterval)
      {
        previousMillis1 = millis();
        UpdateWeather();

      }

      if (millis() - previousMillis2 >= Timeinterval)
      {
        previousMillis2 = millis();
        UpdateTime_RTC();
      }
    }
    delay(500);
  }
  if (WiFi.status() != WL_CONNECTED)
  {
    if (wifi_flag == 0)
    {
      Serial.println("成功复位");
      ESP.restart();
    }
  }


}
boolean doDelayMillisTime(long interval , boolean state) {
  unsigned long currentMillis = millis();
  if (currentMillis - previousMillis >= interval) {
    previousMillis = currentMillis;
    state = !state;
  }
  return state;
}
void restCallback(TimerHandle_t xTimer ) {  //长时间不访问WIFI Config 将复位设备

  resr_count_down --;

  Serial.print("resr_count_down: ");

  Serial.println(resr_count_down);

  if (resr_count_down < 1) {

    ESP.restart();

  }

}

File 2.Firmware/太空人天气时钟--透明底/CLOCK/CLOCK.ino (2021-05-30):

/*
 * ***********************************************
 * 简易太空人时钟代码 
 * 作者抖音号：d88880
 * 欢迎随意传播修改，但请保留本段注释，且不要用于商业目的。
 * ***********************************************
 * 程序硬件介绍 nodemcu + LCD屏幕（ST7789）
 * 
 * 自动根据当前IP获取相应天气
 * 代码有点烂凑合着看
 * 时间部分使用NTP同步阿里云服务器时间
 * 天气部分从中国天气网上扒下来的，具体是否能长期使用无法确定
 * 
 * 屏幕使用的中景园1.54寸240分辨率全彩屏幕，7、8、10针脚的屏应该都可以，具体请自己参考引脚定义
 * 搞废了别找我就好，有问题可以在抖音评论区留言
 * 
 */
#include "ArduinoJson.h"

#include <TimeLib.h>
#include <WiFi.h>
#include <HTTPClient.h>
//#include <ESP8266WiFi.h>
#include <WiFiUdp.h>
//#include <ESP8266HTTPClient.h>
#define LCD_BL_PIN 5
#define LCD_BL_PWM_CHANNEL 0

//---------------修改此处""内的信息--------------------
const char ssid[] = "77's";        //WIFI名称 修改这2个就可以了
const char pass[] = "123456789";    //WIFI密码
//----------------------------------------------------

#include "font/ZdyLwFont_20.h"
#include "font/FxLED_32.h"

#include "img/pangzi/i0.h"
#include "img/pangzi/i1.h"
#include "img/pangzi/i2.h"
#include "img/pangzi/i3.h"
#include "img/pangzi/i4.h"
#include "img/pangzi/i5.h"
#include "img/pangzi/i6.h"
#include "img/pangzi/i7.h"
#include "img/pangzi/i8.h"
#include "img/pangzi/i9.h"

#include "img/temperature.h"
#include "img/humidity.h"
#include "img/watch_top.h"
#include "img/watch_bottom.h"
#include "img/misaka.h"

#include <TFT_eSPI.h> 
#include <SPI.h>

TFT_eSPI tft = TFT_eSPI();  // 引脚请自行配置tft_espi库中的 User_Setup.h文件
TFT_eSprite clk = TFT_eSprite(&tft);



#include <TJpg_Decoder.h>

uint32_t targetTime = 0;   
byte omm = 99;
boolean initial = 1;
byte xcolon = 0;
unsigned int colour = 0;

uint16_t bgColor = 0x0000;
String cityCode = "101210101";  //天气城市代码

//NTP服务器
static const char ntpServerName[] = "ntp6.aliyun.com";
const int timeZone = 8;     //东八区


WiFiUDP Udp;
unsigned int localPort = 8000;
float duty=0;
time_t getNtpTime();
void digitalClockDisplay();
void printDigits(int digits);
String num2str(int digits);
void sendNTPpacket(IPAddress &address);


bool tft_output(int16_t x, int16_t y, uint16_t w, uint16_t h, uint16_t* bitmap)
{
  if ( y >= tft.height() ) return 0;
  tft.pushImage(x, y, w, h, bitmap);
  // Return 1 to decode next block
  return 1;
}

byte loadNum = 6;
void loading(byte delayTime){
  clk.setColorDepth(8);
  
  clk.createSprite(200, 50);
  clk.fillSprite(0x0000);

  clk.drawRoundRect(0,0,200,16,8,0xFFFF);
  clk.fillRoundRect(3,3,loadNum,10,5,0xFFFF);
  clk.setTextDatum(CC_DATUM);
  clk.setTextColor(TFT_GREEN, 0x0000); 
  clk.drawString("Connecting to WiFi",100,40,2);
  clk.pushSprite(20,110);
  clk.deleteSprite();
  loadNum += 1;
  if(loadNum>=194){
    loadNum = 194;
  }
  delay(delayTime);
}

void setup()
{
  Serial.begin(9600);

  ledcSetup(LCD_BL_PWM_CHANNEL, 5000, 8);
  ledcAttachPin(LCD_BL_PIN, LCD_BL_PWM_CHANNEL);
  duty = constrain(0.5, 0, 1);          //LCD亮度，大了小心电源芯片发热
  duty = 1 - duty;
  ledcWrite(LCD_BL_PWM_CHANNEL, (int)(duty * 255));
  tft.begin(); /* TFT init */
  tft.setRotation(4); /* mirror */
//  tft.init();
//  tft.setRotation(0);
  tft.fillScreen(0x0000);
  tft.setTextColor(TFT_BLACK, bgColor);

  targetTime = millis() + 1000; 

  Serial.print("正在连接WIFI ");
  Serial.println(ssid);
  WiFi.begin(ssid, pass);

  while (WiFi.status() != WL_CONNECTED) {
    for(byte n=0;n<10;n++){ //每500毫秒检测一次状态
      loading(50);
    }
  }
  while(loadNum < 194){ //让动画走完
    loading(1);
  }

  Serial.print("本地IP： ");
  Serial.println(WiFi.localIP());
  //Serial.println("启动UDP");
  Udp.begin(localPort);
  //Serial.print("端口号: ");
  //Serial.println(Udp.localPort());
  //Serial.println("等待同步...");
  setSyncProvider(getNtpTime);
  setSyncInterval(300);

  
  TJpgDec.setJpgScale(1);
  TJpgDec.setSwapBytes(true);
  TJpgDec.setCallback(tft_output);

  TJpgDec.drawJpg(0,0,misaka, sizeof(misaka));
  delay(1000); 
  
  TJpgDec.drawJpg(0,0,watchtop, sizeof(watchtop));
  TJpgDec.drawJpg(0,220,watchbottom, sizeof(watchbottom));

  
  //绘制一个视口
  tft.setViewport(0, 20, 240, 200);
  tft.fillScreen(0x0000);
  tft.fillRoundRect(0,0,240,200,5,bgColor);//实心圆角矩形
  //tft.resetViewport();

  //绘制线框
  tft.drawFastHLine(0,34,240,TFT_WHITE);
  
  tft.drawFastVLine(150,0,34,TFT_WHITE);
  
  tft.drawFastHLine(0,166,240,TFT_WHITE);
  
  tft.drawFastVLine(60,166,34,TFT_WHITE);
  tft.drawFastVLine(160,166,34,TFT_WHITE);

  getCityCode();  //获取城市代码
  
  TJpgDec.drawJpg(161,171,temperature, sizeof(temperature));  //温度图标
  TJpgDec.drawJpg(159,130,humidity, sizeof(humidity));  //湿度图标
  
}

time_t prevDisplay = 0; // 显示时间
unsigned long weaterTime = 0;

void loop(){
  
  if (now() != prevDisplay) {
    prevDisplay = now();
    digitalClockDisplay();
  }

  
  if(millis() - weaterTime > 300000){ //5分钟更新一次天气
    weaterTime = millis();
    getCityWeater();
  }
  scrollBanner();
  imgAnim();
}


// 发送HTTP请求并且将服务器响应通过串口输出
void getCityCode(){
 String URL = "http://wgeo.weather.com.cn/ip/?_="+String(now());
  //创建 HTTPClient 对象
  HTTPClient httpClient;
 
  //配置请求地址。此处也可以不使用端口号和PATH而单纯的
  httpClient.begin(URL); 
  
  //设置请求头中的User-Agent
  httpClient.setUserAgent("Mozilla/5.0 (iPhone; CPU iPhone OS 11_0 like Mac OS X) AppleWebKit/604.1.38 (KHTML, like Gecko) Version/11.0 Mobile/15A372 Safari/604.1");
  httpClient.addHeader("Referer", "http://www.weather.com.cn/");
 
  //启动连接并发送HTTP请求
  int httpCode = httpClient.GET();
  Serial.print("Send GET request to URL: ");
  Serial.println(URL);
  
  //如果服务器响应OK则从服务器获取响应体信息并通过串口输出
  if (httpCode == HTTP_CODE_OK) {
    String str = httpClient.getString();
    
    int aa = str.indexOf("id=");
    if(aa>-1){
      //  cityCode = str.substring(aa+4,aa+4+9);
       Serial.println(cityCode); 
       getCityWeater();
    }else{
      Serial.println("获取城市代码失败");  
    }
    
    
  } else {
    Serial.println("请求城市代码错误：");
    Serial.println(httpCode);
  }
 
  //关闭ESP8266与服务器连接
  httpClient.end();
}
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

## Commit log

2021-05-30 Update README.md
    添加项目简介
2021-05-31 Update BOM
    [MainBoard.xlsx, 销售清单.xlsx]
